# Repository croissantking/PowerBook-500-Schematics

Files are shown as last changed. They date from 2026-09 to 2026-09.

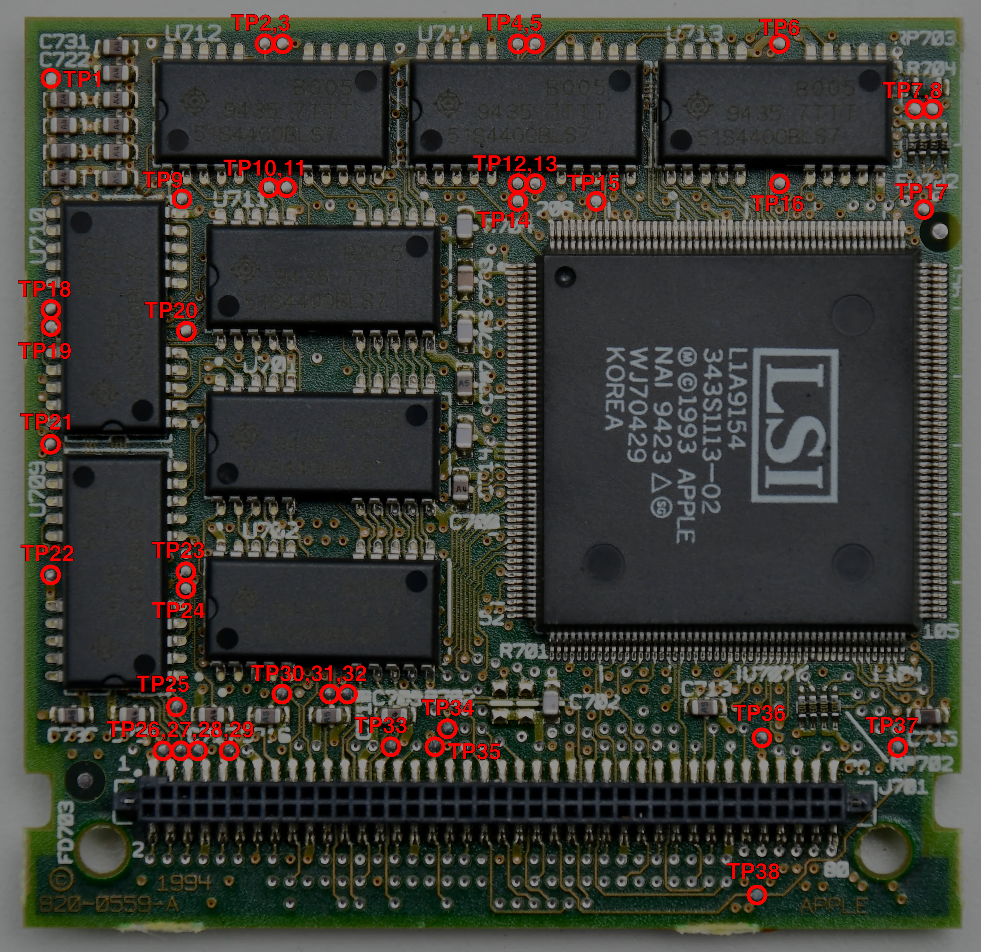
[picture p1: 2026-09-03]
docs/reference/test-points.jpg

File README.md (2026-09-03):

# Macintosh PowerBook 500 Series CPU Card Schematics

The PowerBook 500 Series is a very popular laptop with hobbyists. Lately I have been tinkering a lot with mine. Unfortunately no schematics are available which limits repair and modding potential. In an effort to remedy this, I studied a CPU card with a multimeter and drew up schematics in KiCad.

The CPU card is essentially identical across all five models: the 520, 520c, 540, 540c and 550c.

The drawings are a work in progress so I expect there to be some errors, although hopefully just minor ones.

Follow this link to jump to the [PDF Schematics Directory](https://github.com/croissantking/PowerBook-500-Schematics/tree/main/docs).

### Acknowledgements

With thanks to oldcrap.org for permission to re-use their PowerBook 540c CPU card scans.

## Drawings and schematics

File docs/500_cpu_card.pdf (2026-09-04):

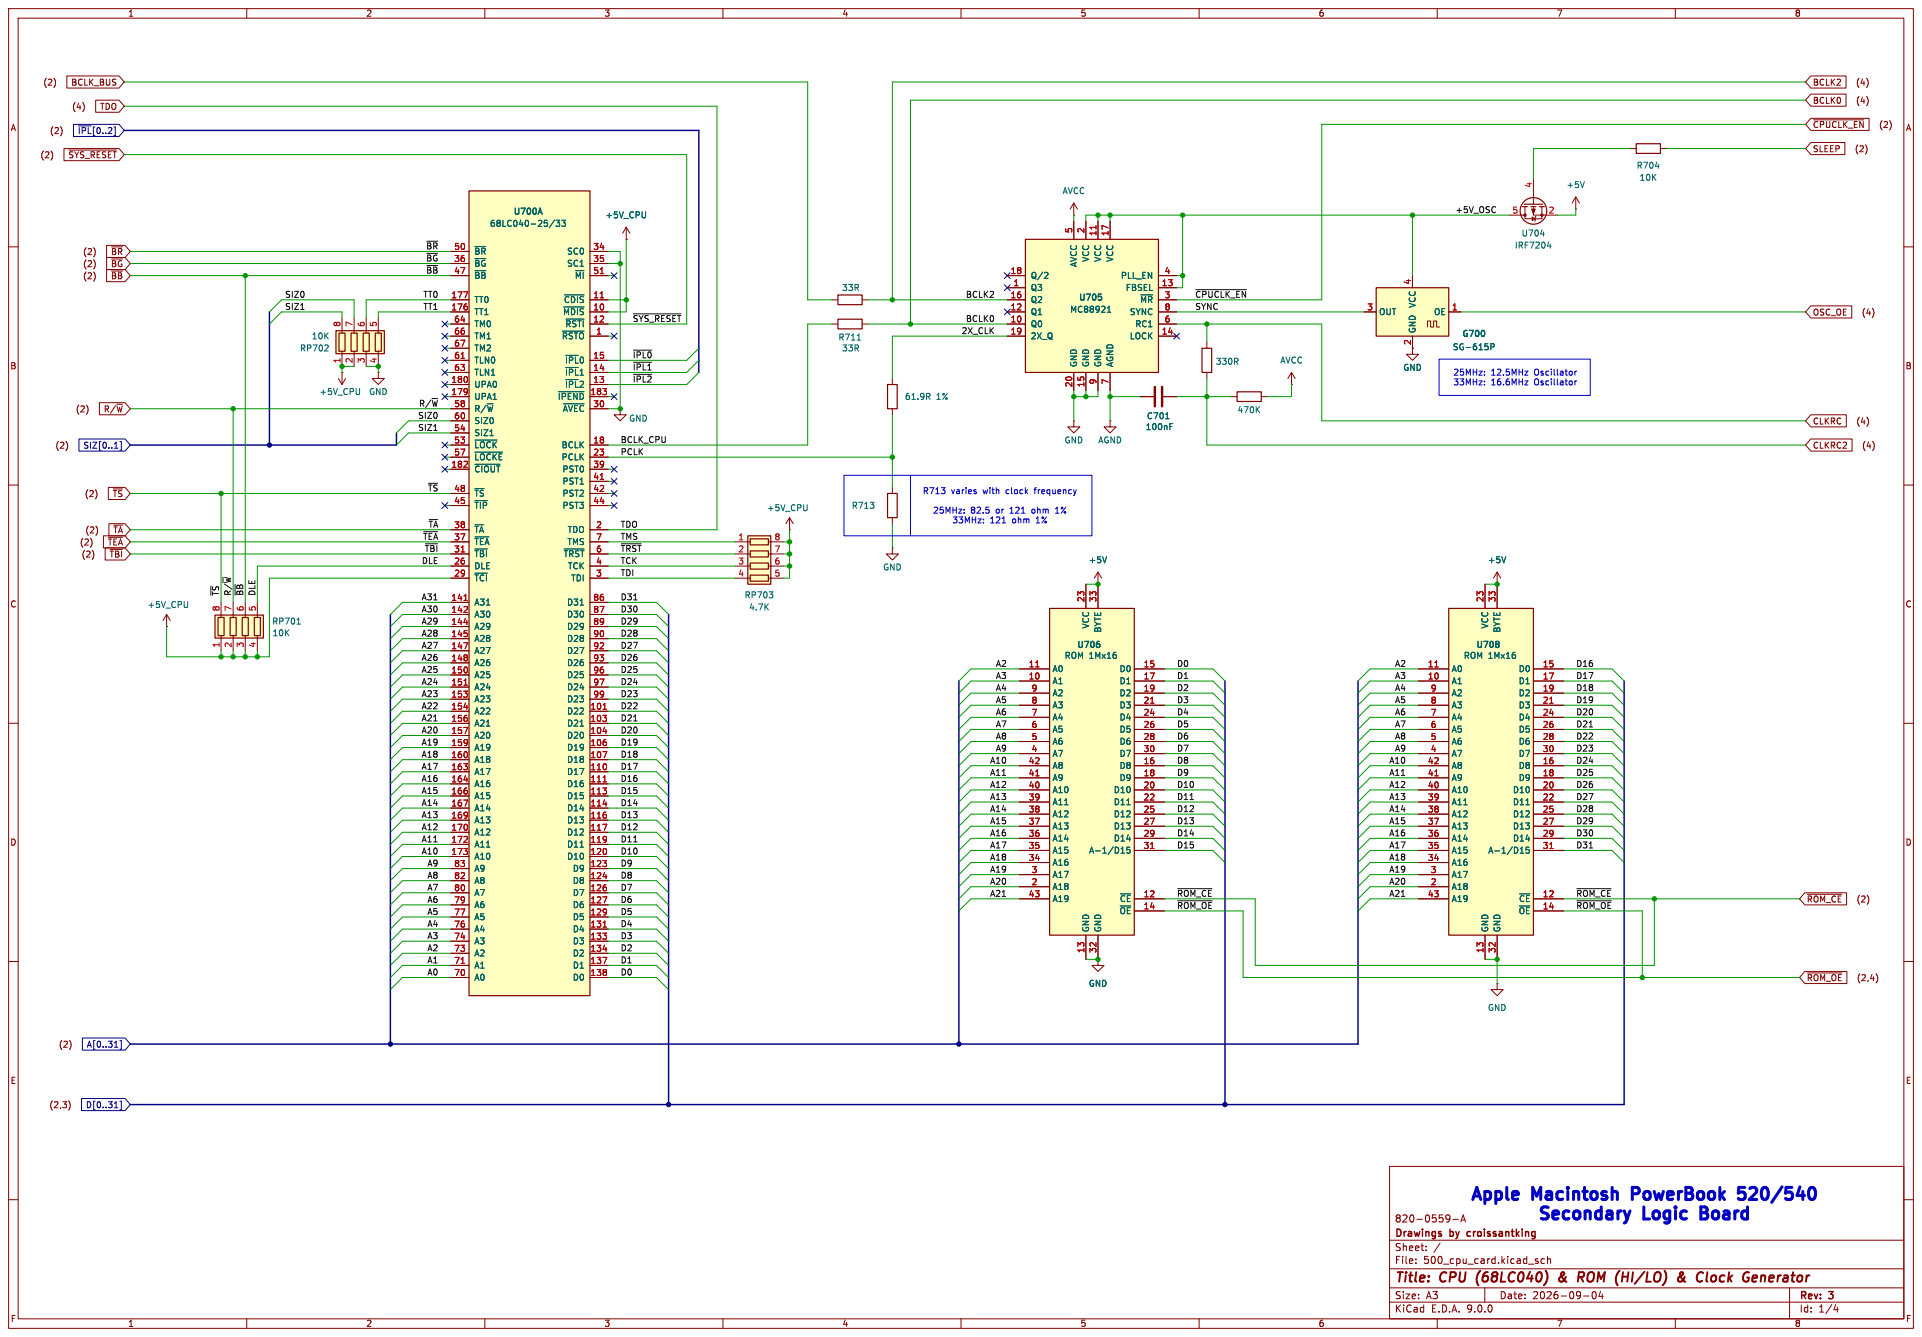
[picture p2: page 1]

~{BR} 50 ~{BG} 36 ~{BB} 47 TT0 177 TT1 176 TM0 64 TM1 66 TM2 67 TLN0 61 TLN1 63 UPA0 180 UPA1 179 R/~{W} 58 SIZ0 60 SIZ1 54 ~{LOCK} 53 ~{LOCKE} 57 ~{CIOUT} 182 ~{TS} 48 ~{TIP} 45 ~{TA} 38 ~{TEA} 37 ~{TBI} 31 DLE 26 ~{TCI} 29 A31 141 A30 142 A29 144 A28 145 A27 147 A26 148 A25 150 A24 151 A23 153 A22 154 A21 156 A20 157 A19 159 A18 160 A17 163 A16 164 A15 166 A14 167 A13 169 A12 170 A11 172 A10 173 A9 83 A8 82 A7 80 A6 79 A5 77 A4 76 A3 74 A2 73 A1 71 A0 70

68LC040-25/33 ~{BR} 50 ~{BG} 36 ~{BB} 47 TT0 177 TT1 176 TM0 64 TM1 66 TM2 67 TLN0 61 TLN1 63 UPA0 180 UPA1 179 R/~{W} 58 SIZ0 60 SIZ1 54 ~{LOCK} 53 ~{LOCKE} 57 ~{CIOUT} 182 ~{TS} 48 ~{TIP} 45 ~{TA} 38 ~{TEA} 37 ~{TBI} 31 DLE 26 ~{TCI} 29 A31 141 A30 142 A29 144 A28 145 A27 147 A26 148 A25 150 A24 151 A23 153 A22 154 A21 156 A20 157 A19 159 A18 160 A17 163 A16 164 A15 166 A14 167 A13 169 A12 170 A11 172 A10 173 A9 83 A8 82 A7 80 A6 79 A5 77 A4 76 A3 74 A2 73 A1 71 A0 70
SC0 34 SC1 35 ~{MI}51 ~{CDIS}11 ~{MDIS}10 ~{RSTI}12 ~{RSTO}1 ~{IPL}015 ~{IPL}114 ~{IPL}213 ~{IPEND}183 ~{AVEC}30 BCLK 18 PCLK 23 PST0 39 PST1 41 PST2 42 PST3 44 TDO 2 TMS 7 ~{TRST}6 TCK 4 TDI 3 D31 86 D30 87 D29 89 D28 90 D27 92 D26 93 D25 96 D24 97 D23 99 D22 101 D21 103 D20 104 D19 106 D18 107 D17 110 D16 111 D15 113 D14 114 D13 116 D12 117 D11 119 D10 120 D9 123 D8 124 D7 126 D6 127 D5 129 D4 131 D3 133 D2 134 D1 137 D0 138

2 GND 15 AVCC
25MHz: 12.5MHz Oscillator 33MHz: 16.6MHz Oscillator Apple Macintosh PowerBook 520/540

A21 R713 varies with clock frequency 25MHz: 82.5 or 121 ohm 1%

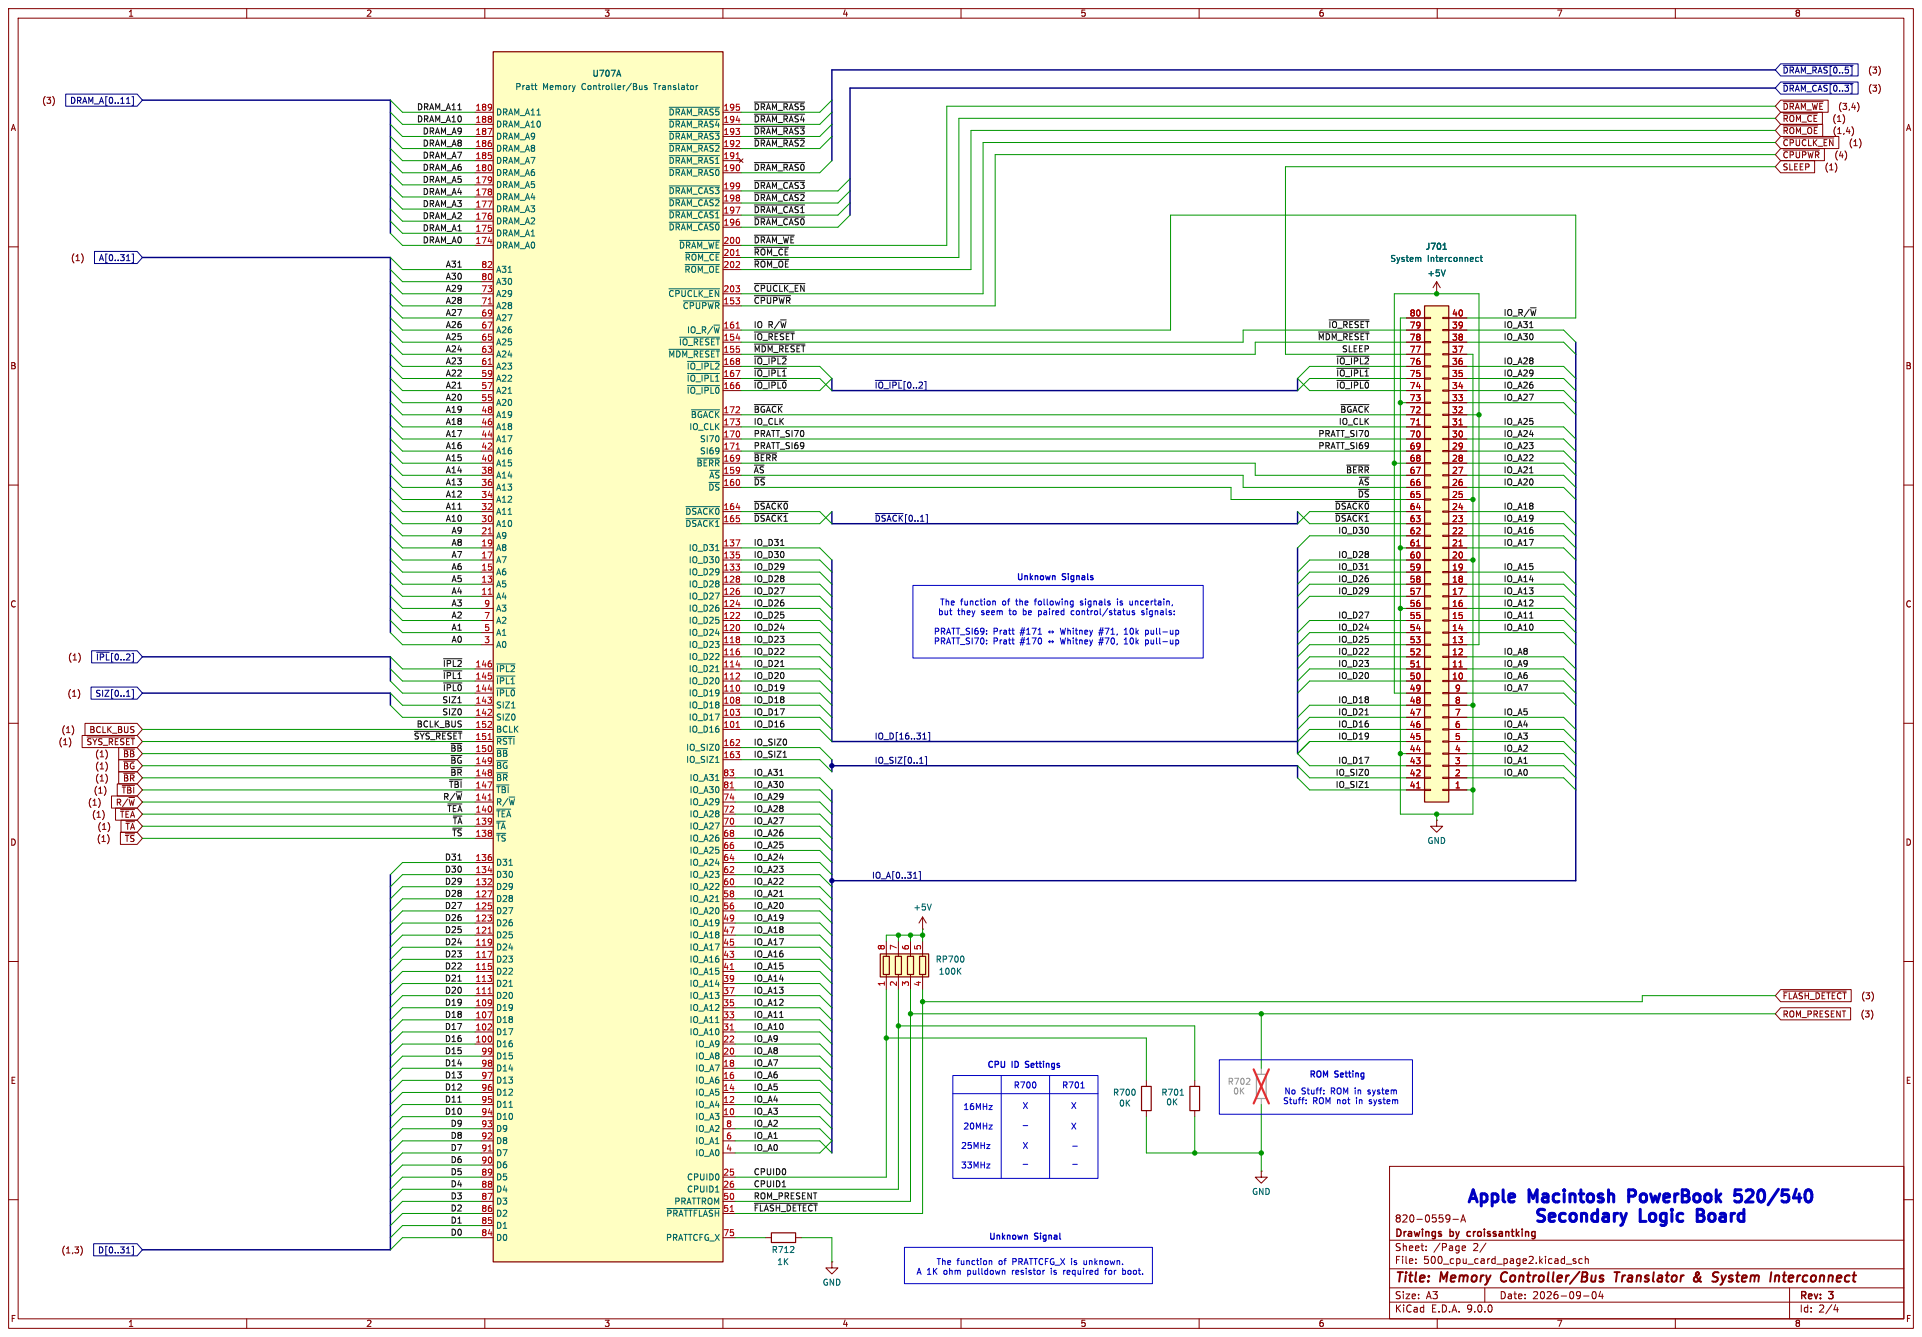
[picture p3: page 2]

Stuff: ROM not in system

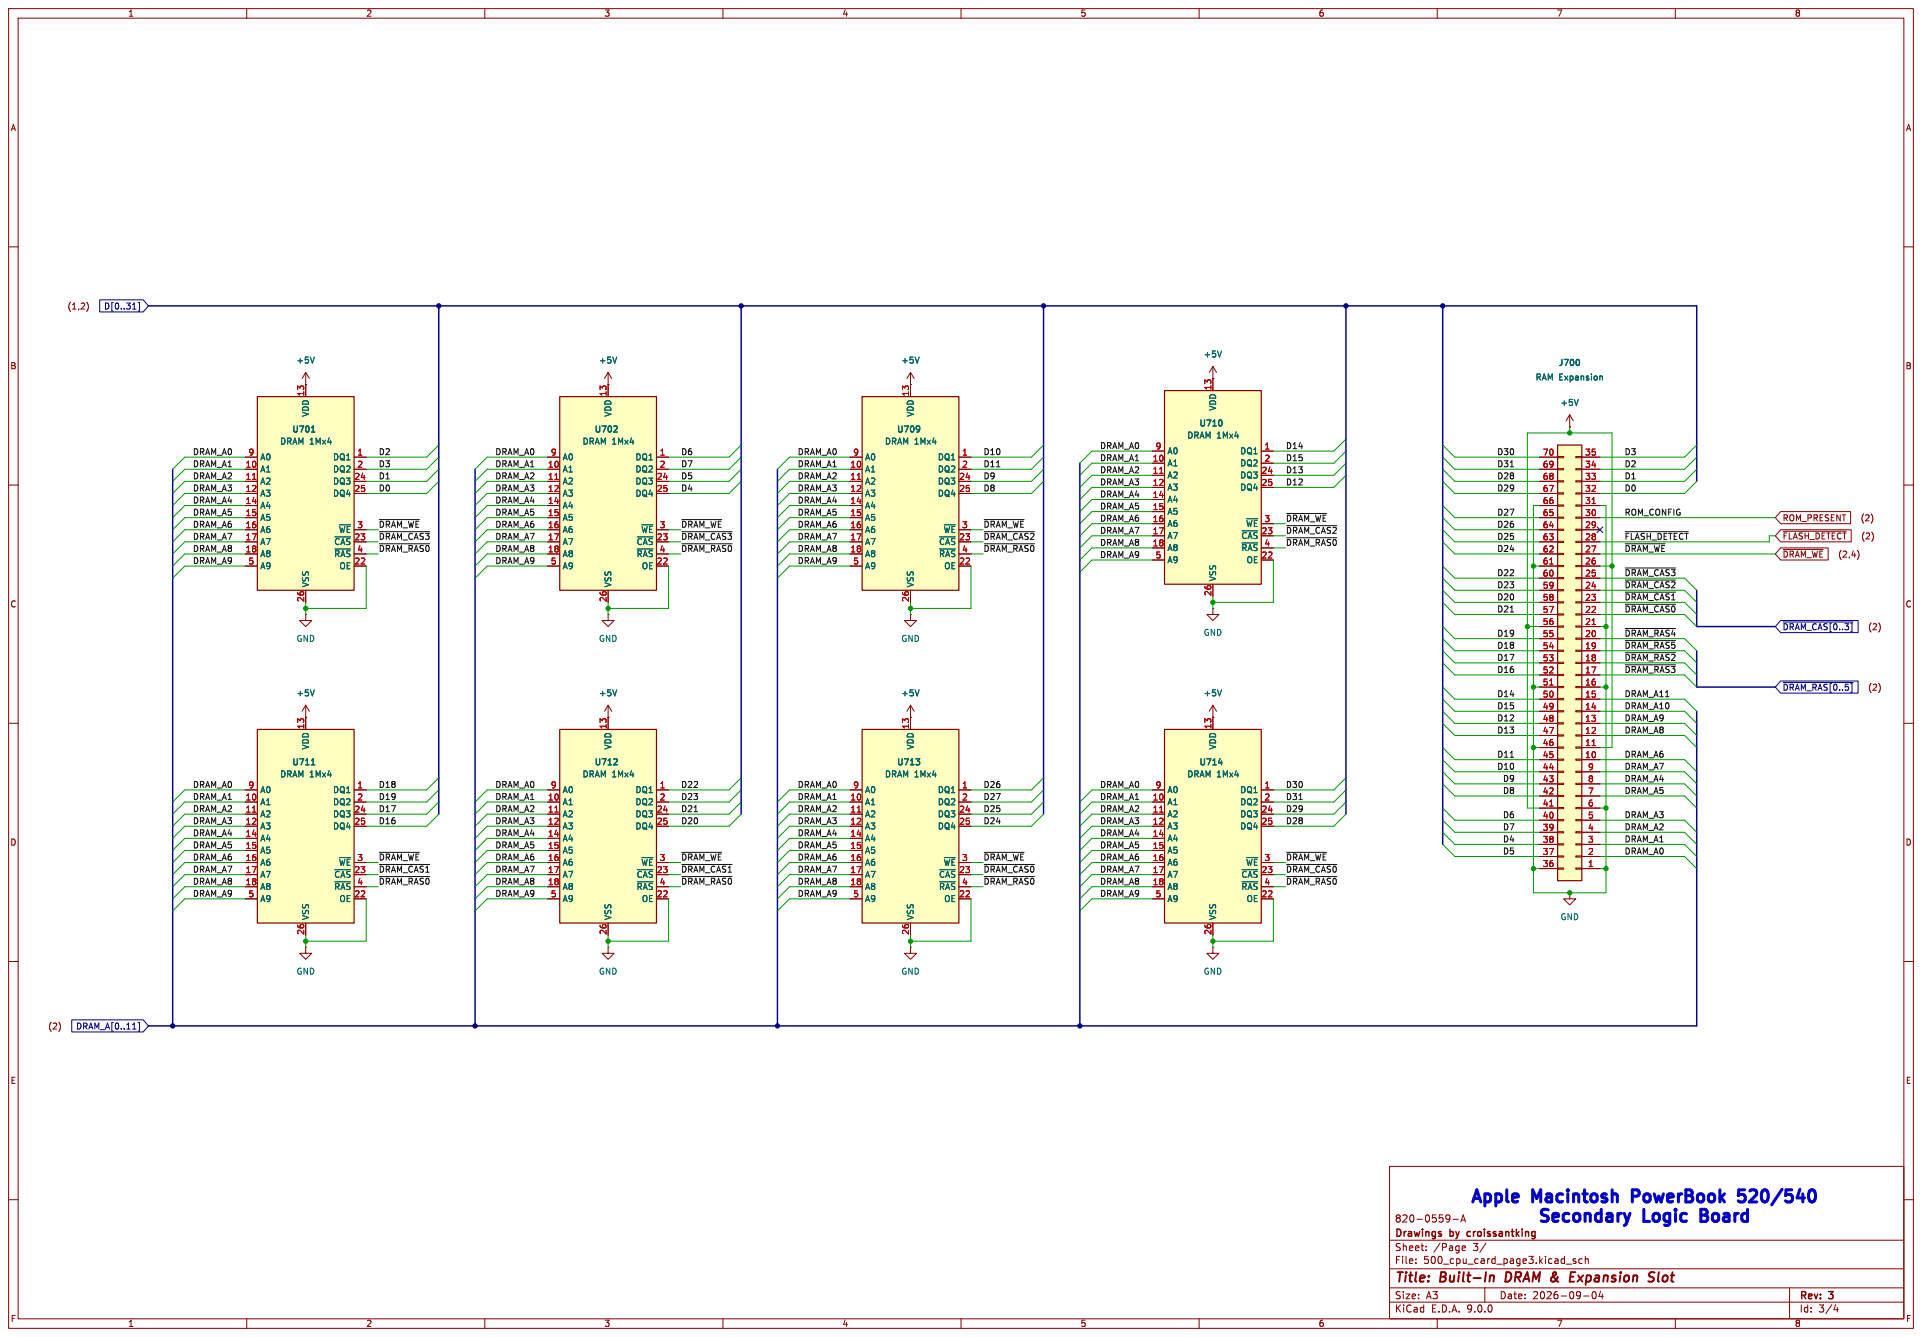
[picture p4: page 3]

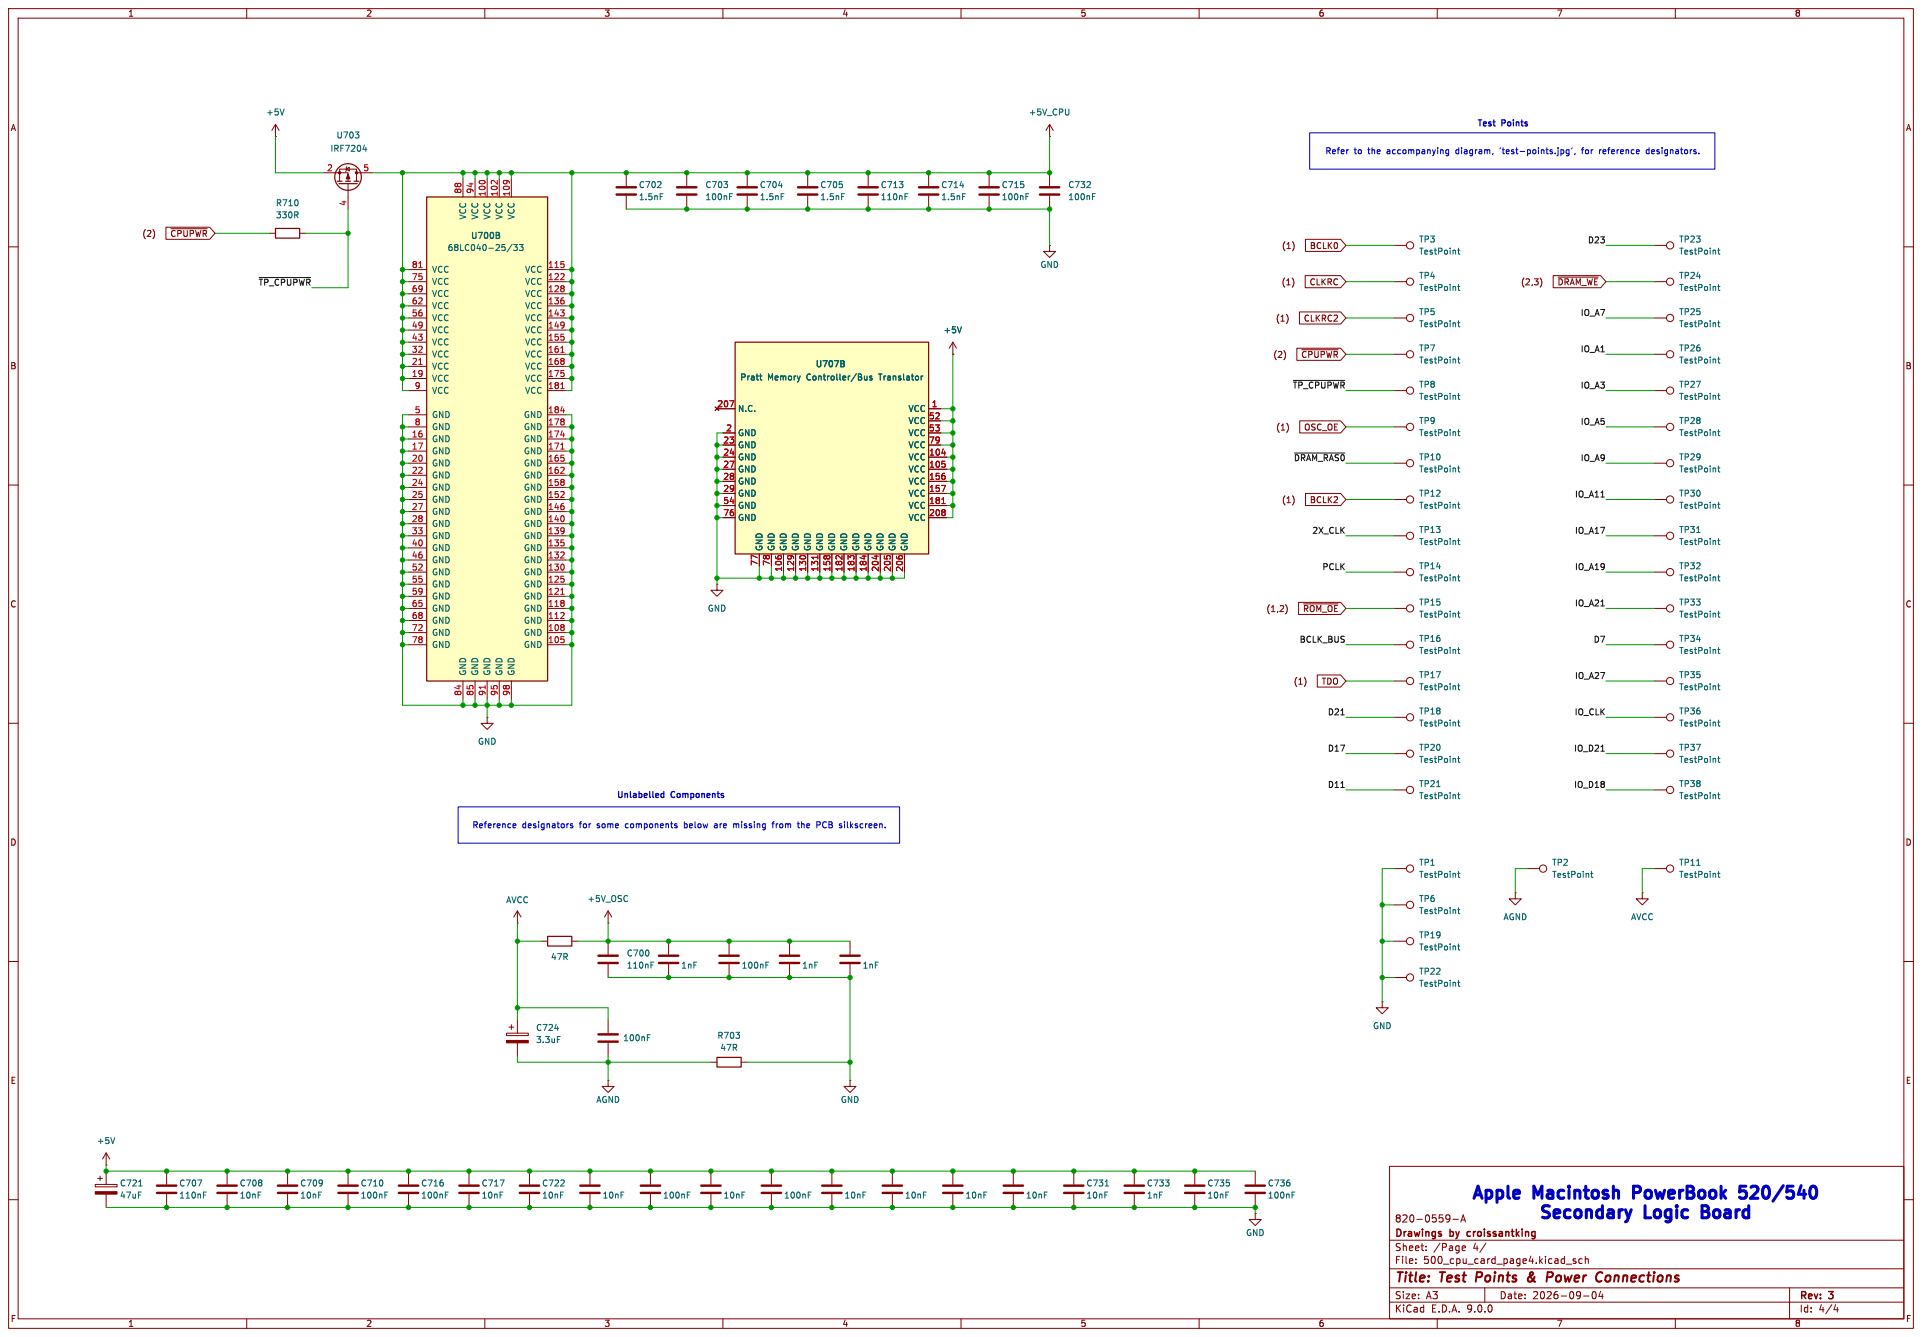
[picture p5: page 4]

TP38 TestPoint TP35 TestPoint TP34 TestPoint TP33 TestPoint TP32 TestPoint TP31 TestPoint C732

TP20 TestPoint TP21 TestPoint TP10 TestPoint TP12 TestPoint TP13 TestPoint

Id: 4/4 Title: Test Points & Power Connections

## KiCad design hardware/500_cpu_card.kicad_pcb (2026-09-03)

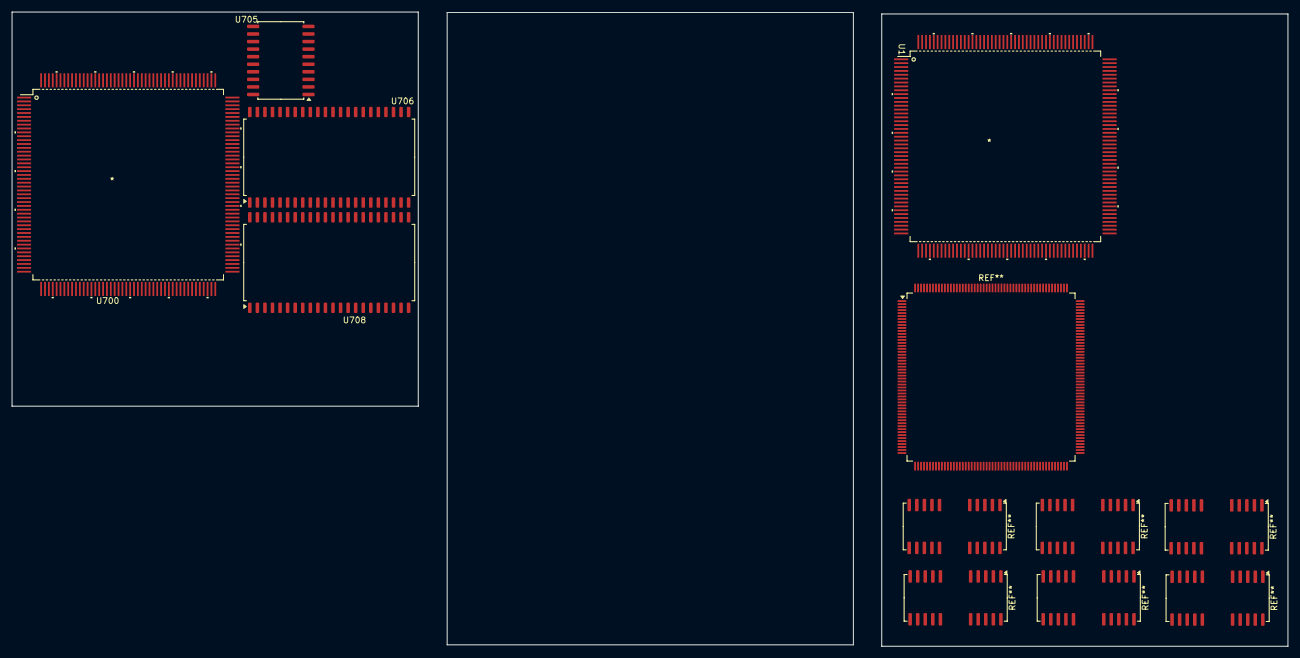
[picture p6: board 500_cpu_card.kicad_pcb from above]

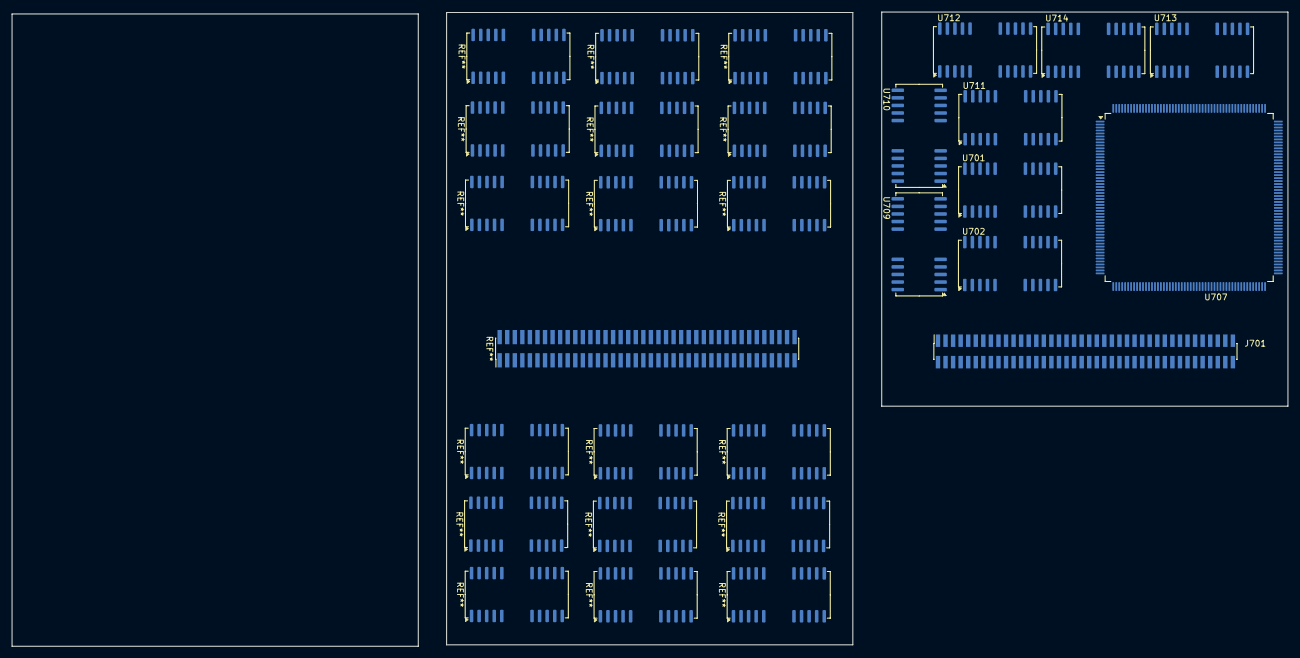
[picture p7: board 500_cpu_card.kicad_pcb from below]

Board: 6 copper layers, 214.3 x 106.5 mm, 15 parts (10 on the bottom side), 161 nets, no tracks yet.

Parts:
J701: System Interconnect; PinSocket_2x40_P1.27mm_Vertical_SMD
U1: MC68040FE; Mot_QFP184_HandSolder
U700: XC68LC040FE25/33; Mot_QFP184_HandSolder
U701, U702, U709, U710, U711, U712, U713, U714: DRAM 1Mx4; SOJ-26
U705: MC88921; SOIC-20W_7.5x12.8mm_P1.27mm
U706, U708: ROM 1Mx16; SOP-44_12.6x28.5mm_P1.27mm
U707: Pratt Memory Controller/Bus Translator; PQFP-208_28x28mm_P0.5mm

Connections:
+5V: J701.13 (VCC), J701.32 (VCC), J701.49 (VCC), J701.68 (VCC), U701.13 (VDD), U702.13 (VDD), U706.23 (VCC), U706.33 (BYTE), U707.1 (VCC), U707.52 (VCC), U707.53 (VCC), U707.79 (VCC), U707.104 (VCC), U707.105 (VCC), U707.156 (VCC), U707.157 (VCC), U707.181 (VCC), U707.208 (VCC), U708.23 (VCC), U708.33 (BYTE), U709.13 (VDD), U710.13 (VDD), U711.13 (VDD), U712.13 (VDD), U713.13 (VDD), U714.13 (VDD)
+5V_CPU: U700.9 (VCC), U700.10 (~MDIS), U700.11 (~CDIS), U700.19 (VCC), U700.21 (VCC), U700.29 (~TCI), U700.32 (VCC), U700.43 (VCC), U700.49 (VCC), U700.56 (VCC), U700.62 (VCC), U700.69 (VCC), U700.75 (VCC), U700.81 (VCC), U700.88 (VCC), U700.94 (VCC), U700.100 (VCC), U700.102 (VCC), U700.109 (VCC), U700.115 (VCC), U700.122 (VCC), U700.128 (VCC), U700.136 (VCC), U700.143 (VCC), U700.149 (VCC), U700.155 (VCC), U700.161 (VCC), U700.168 (VCC), U700.175 (VCC), U700.181 (VCC)
/Page 2/IO_69: J701.69 (?), U707.171 (IO_69)
/Page 2/IO_70: J701.70 (?), U707.170 (IO_70)
/Page 2/IO_A0: J701.2 (030_A0), U707.4 (IO_A0)
/Page 2/IO_A1: J701.3 (030_A1), U707.6 (IO_A1)
/Page 2/IO_A2: J701.4 (030_A2), U707.8 (IO_A2)
/Page 2/IO_A3: J701.5 (030_A3), U707.10 (IO_A3)
/Page 2/IO_A4: J701.6 (030_A4), U707.12 (IO_A4)
/Page 2/IO_A5: J701.7 (030_A5), U707.14 (IO_A5)
/Page 2/IO_A6: J701.10 (030_A6), U707.16 (IO_A6)
/Page 2/IO_A7: J701.9 (030_A7), U707.18 (IO_A7)
/Page 2/IO_A8: J701.12 (030_A8), U707.20 (IO_A8)
/Page 2/IO_A9: J701.11 (030_A9), U707.22 (IO_A9)
/Page 2/IO_A10: J701.14 (030_A10), U707.31 (IO_A10)
/Page 2/IO_A11: J701.15 (030_A11), U707.33 (IO_A11)
/Page 2/IO_A12: J701.16 (030_A12), U707.35 (IO_A12)
/Page 2/IO_A13: J701.17 (030_A13), U707.37 (IO_A13)
/Page 2/IO_A14: J701.18 (030_A14), U707.39 (IO_A14)
/Page 2/IO_A15: J701.19 (030_A15), U707.41 (IO_A15)
/Page 2/IO_A16: J701.22 (030_A16), U707.43 (IO_A16)
/Page 2/IO_A17: J701.21 (030_A17), U707.45 (IO_A17)
/Page 2/IO_A18: J701.24 (030_A18), U707.47 (IO_A18)
/Page 2/IO_A19: J701.23 (030_A19), U707.49 (IO_A19)
/Page 2/IO_A20: J701.26 (030_A20), U707.56 (IO_A20)
/Page 2/IO_A21: J701.27 (030_A27), U707.58 (IO_A21)
/Page 2/IO_A22: J701.28 (030_A22), U707.60 (IO_A22)
/Page 2/IO_A23: J701.29 (030_A23), U707.62 (IO_A23)
/Page 2/IO_A24: J701.30 (030_A24), U707.64 (IO_A24)
/Page 2/IO_A25: J701.31 (030_A25), U707.66 (IO_A25)
/Page 2/IO_A26: J701.34 (030_A36), U707.68 (IO_A26)
/Page 2/IO_A27: J701.33 (030_A27), U707.70 (IO_A27)
/Page 2/IO_A28: J701.36 (030_A28), U707.72 (IO_A28)
/Page 2/IO_A29: J701.35 (030_A29), U707.74 (IO_A29)
/Page 2/IO_A30: J701.38 (030_A30), U707.81 (IO_A30)
/Page 2/IO_A31: J701.39 (030_A31), U707.83 (IO_A31)
/Page 2/IO_CLK: J701.71 (IO_CLK), U707.173 (IO_CLK)
/Page 2/IO_D16: J701.46 (030_D16), U707.101 (IO_D16)
/Page 2/IO_D17: J701.43 (030_D17), U707.103 (IO_D17)
/Page 2/IO_D18: J701.48 (030_D18), U707.108 (IO_D18)
/Page 2/IO_D19: J701.45 (030_D19), U707.110 (IO_D19)
/Page 2/IO_D20: J701.50 (030_D20), U707.112 (IO_D20)
/Page 2/IO_D21: J701.47 (030_D21), U707.114 (IO_D21)
/Page 2/IO_D22: J701.52 (030_D22), U707.116 (IO_D22)
/Page 2/IO_D23: J701.51 (030_D23), U707.118 (IO_D23)
/Page 2/IO_D24: J701.54 (030_D24), U707.120 (IO_D24)
/Page 2/IO_D25: J701.53 (030_D25), U707.122 (IO_D25)
/Page 2/IO_D26: J701.58 (030_D26), U707.124 (IO_D26)
/Page 2/IO_D27: J701.55 (030_D27), U707.126 (IO_D27)
/Page 2/IO_D28: J701.60 (030_D28), U707.128 (IO_D28)
/Page 2/IO_D29: J701.57 (030_D29), U707.133 (IO_D29)
/Page 2/IO_D30: J701.62 (030_D30), U707.135 (IO_D30)
/Page 2/IO_D31: J701.59 (030_D31), U707.137 (IO_D31)
/Page 2/IO_SIZ0: J701.42 (030_SIZ0), U707.162 (IO_SIZ0)
/Page 2/IO_SIZ1: J701.41 (030_SIZ1), U707.163 (IO_SIZ1)
/Page 2/~AS: J701.66 (~AS), U707.159 (~AS)
/Page 2/~BERR: J701.67 (~BERR), U707.169 (~BERR)
/Page 2/~BGACK: J701.72 (~BGACK), U707.172 (~BGACK)
/Page 2/~DSACK0: J701.64 (~DSACK0), U707.164 (~DSACK0)
/Page 2/~DSACK1: J701.63 (~DSACK1), U707.165 (~DSACK1)
/Page 2/~DS: J701.65 (~DS), U707.160 (~DS)
/Page 2/~IO_IPL0: J701.74 (~030_IPL0), U707.166 (~IO_IPL0)
/Page 2/~IO_IPL1: J701.75 (~030_IPL1), U707.167 (~IO_IPL1)
/Page 2/~IO_IPL2: J701.76 (~030_IPL2), U707.168 (~IO_IPL2)
/Page 2/~IO_RESET: J701.79 (~IO_RESET), U707.154 (~IO_RESET)
/Page 2/~MDM_RESET: J701.78 (~MDM_RESET), U707.155 (~MDM_RESET)
/Page 3/A0: U701.9 (A0), U702.9 (A0), U709.9 (A0), U710.9 (A0), U711.9 (A0), U712.9 (A0), U713.9 (A0), U714.9 (A0)
/Page 3/A1: U701.10 (A1), U702.10 (A1), U709.10 (A1), U710.10 (A1), U711.10 (A1), U712.10 (A1), U713.10 (A1), U714.10 (A1)
/Page 3/A2: U701.11 (A2), U702.11 (A2), U709.11 (A2), U710.11 (A2), U711.11 (A2), U712.11 (A2), U713.11 (A2), U714.11 (A2)
/Page 3/A3: U701.12 (A3), U702.12 (A3), U709.12 (A3), U710.12 (A3), U711.12 (A3), U712.12 (A3), U713.12 (A3), U714.12 (A3)
/Page 3/A4: U701.14 (A4), U702.14 (A4), U709.14 (A4), U710.14 (A4), U711.14 (A4), U712.14 (A4), U713.14 (A4), U714.14 (A4)
/Page 3/A5: U701.15 (A5), U702.15 (A5), U709.15 (A5), U710.15 (A5), U711.15 (A5), U712.15 (A5), U713.15 (A5), U714.15 (A5)
/Page 3/A6: U701.16 (A6), U702.16 (A6), U709.16 (A6), U710.16 (A6), U711.16 (A6), U712.16 (A6), U713.16 (A6), U714.16 (A6)
/Page 3/A7: U701.17 (A7), U702.17 (A7), U709.17 (A7), U710.17 (A7), U711.17 (A7), U712.17 (A7), U713.17 (A7), U714.17 (A7)
/Page 3/A8: U701.18 (A8), U702.18 (A8), U709.18 (A8), U710.18 (A8), U711.18 (A8), U712.18 (A8), U713.18 (A8), U714.18 (A8)
/Page 3/A9: U701.5 (A9), U702.5 (A9), U709.5 (A9), U710.5 (A9), U711.5 (A9), U712.5 (A9), U713.5 (A9), U714.5 (A9)
/Page 3/~DRAM_CAS0: U713.23 (~CAS), U714.23 (~CAS)
/Page 3/~DRAM_CAS1: U711.23 (~CAS), U712.23 (~CAS)
/Page 3/~DRAM_CAS2: U709.23 (~CAS), U710.23 (~CAS)
/Page 3/~DRAM_CAS3: U701.23 (~CAS), U702.23 (~CAS)
/Page 3/~DRAM_RAS0: U701.4 (~RAS), U702.4 (~RAS), U709.4 (~RAS), U710.4 (~RAS), U711.4 (~RAS), U712.4 (~RAS), U713.4 (~RAS), U714.4 (~RAS)
/Page 3/~DRAM_WE: U701.3 (~WE), U702.3 (~WE), U709.3 (~WE), U710.3 (~WE), U711.3 (~WE), U712.3 (~WE), U713.3 (~WE), U714.3 (~WE)
/~ROM_CE: U706.12 (~CE), U708.12 (~CE)
/~ROM_OE: U706.14 (~OE), U708.14 (~OE)
A0: U700.70 (A0), U706.11 (A0), U707.3 (A0), U708.11 (A0)
A1: U700.71 (A1), U706.10 (A1), U707.5 (A1), U708.10 (A1)
A2: U700.73 (A2), U706.9 (A2), U707.7 (A2), U708.9 (A2)
A3: U700.74 (A3), U706.8 (A3), U707.9 (A3), U708.8 (A3)
A4: U700.76 (A4), U706.7 (A4), U707.11 (A4), U708.7 (A4)
A5: U700.77 (A5), U706.6 (A5), U707.13 (A5), U708.6 (A5)
A6: U700.79 (A6), U706.5 (A6), U707.15 (A6), U708.5 (A6)
A7: U700.80 (A7), U706.4 (A7), U707.17 (A7), U708.4 (A7)
A8: U700.82 (A8), U706.42 (A8), U707.19 (A8), U708.42 (A8)
A9: U700.83 (A9), U706.41 (A9), U707.21 (A9), U708.41 (A9)
A10: U700.173 (A10), U706.40 (A10), U707.30 (A10), U708.40 (A10)
A11: U700.172 (A11), U706.39 (A11), U707.32 (A11), U708.39 (A11)
A12: U700.170 (A12), U706.38 (A12), U707.34 (A12), U708.38 (A12)
A13: U700.169 (A13), U706.37 (A13), U707.36 (A13), U708.37 (A13)
A14: U700.167 (A14), U706.36 (A14), U707.38 (A14), U708.36 (A14)
A15: U700.166 (A15), U706.35 (A15), U707.40 (A15), U708.35 (A15)
A16: U700.164 (A16), U706.34 (A16), U707.42 (A16), U708.34 (A16)
A17: U700.163 (A17), U706.3 (A17), U707.44 (A17), U708.3 (A17)
A18: U700.160 (A18), U706.2 (A18), U707.46 (A18), U708.2 (A18)
A19: U700.159 (A19), U706.43 (A19), U707.48 (A19), U708.43 (A19)
A20: U700.157 (A20), U707.55 (A20)
A21: U700.156 (A21), U707.57 (A21)
A22: U700.154 (A22), U707.59 (A22)
A23: U700.153 (A23), U707.61 (A23)
A24: U700.151 (A24), U707.63 (A24)
A25: U700.150 (A25), U707.65 (A25)
A26: U700.148 (A26), U707.67 (A26)
A27: U700.147 (A27), U707.69 (A27)
A28: U700.145 (A28), U707.71 (A28)
A29: U700.144 (A29), U707.73 (A29)
A30: U700.142 (A30), U707.80 (A30)
A31: U700.141 (A31), U707.82 (A31)
D0: U700.138 (D0), U701.25 (DQ4), U706.15 (D0), U707.84 (D0)
D1: U700.137 (D1), U701.24 (DQ3), U706.17 (D1), U707.85 (D1)
D2: U700.134 (D2), U701.1 (DQ1), U706.19 (D2), U707.86 (D2)
D3: U700.133 (D3), U701.2 (DQ2), U706.21 (D3), U707.87 (D3)
D4: U700.131 (D4), U702.25 (DQ4), U706.24 (D4), U707.88 (D4)
D5: U700.129 (D5), U702.24 (DQ3), U706.26 (D5), U707.89 (D5)
D6: U700.127 (D6), U702.1 (DQ1), U706.28 (D6), U707.90 (D6)
D7: U700.126 (D7), U702.2 (DQ2), U706.30 (D7), U707.91 (D7)
D8: U700.124 (D8), U706.16 (D8), U707.92 (D8), U709.25 (DQ4)
D9: U700.123 (D9), U706.18 (D9), U707.93 (D9), U709.24 (DQ3)
D10: U700.120 (D10), U706.20 (D10), U707.94 (D10), U709.1 (DQ1)
D11: U700.119 (D11), U706.22 (D11), U707.95 (D11), U709.2 (DQ2)
D12: U700.117 (D12), U706.25 (D12), U707.96 (D12), U710.25 (DQ4)
D13: U700.116 (D13), U706.27 (D13), U707.97 (D13), U710.24 (DQ3)
D14: U700.114 (D14), U706.29 (D14), U707.98 (D14), U710.1 (DQ1)
D15: U700.113 (D15), U706.31 (A-1/D15), U707.99 (D15), U710.2 (DQ2)
D16: U700.111 (D16), U707.100 (D16), U708.15 (D0), U711.25 (DQ4)
D17: U700.110 (D17), U707.102 (D17), U708.17 (D1), U711.24 (DQ3)
D18: U700.107 (D18), U707.107 (D18), U708.19 (D2), U711.1 (DQ1)
D19: U700.106 (D19), U707.109 (D19), U708.21 (D3), U711.2 (DQ2)
D20: U700.104 (D20), U707.111 (D20), U708.24 (D4), U712.25 (DQ4)
D21: U700.103 (D21), U707.113 (D21), U708.26 (D5), U712.24 (DQ3)
D22: U700.101 (D22), U707.115 (D22), U708.28 (D6), U712.1 (DQ1)
D23: U700.99 (D23), U707.117 (D23), U708.30 (D7), U712.2 (DQ2)
D24: U700.97 (D24), U707.119 (D24), U708.16 (D8), U713.25 (DQ4)
D25: U700.96 (D25), U707.121 (D25), U708.18 (D9), U713.24 (DQ3)
D26: U700.93 (D26), U707.123 (D26), U708.20 (D10), U713.1 (DQ1)
D27: U700.92 (D27), U707.125 (D27), U708.22 (D11), U713.2 (DQ2)
D28: U700.90 (D28), U707.127 (D28), U708.25 (D12), U714.25 (DQ4)
D29: U700.89 (D29), U707.132 (D29), U708.27 (D13), U714.24 (DQ3)
D30: U700.87 (D30), U707.134 (D30), U708.29 (D14), U714.1 (DQ1)
D31: U700.86 (D31), U707.136 (D31), U708.31 (A-1/D15), U714.2 (DQ2)
GND: J701.1 (GND), J701.8 (GND), J701.20 (GND), J701.25 (GND), J701.37 (GND), J701.44 (GND), J701.56 (GND), J701.61 (GND), J701.73 (GND), J701.80 (GND), U700.5 (GND), U700.8 (GND), U700.16 (GND), U700.17 (GND), U700.20 (GND), U700.22 (GND), U700.24 (GND), U700.25 (GND), U700.27 (GND), U700.28 (GND), U700.30 (~AVEC), U700.33 (GND), U700.34 (SC0), U700.35 (SC1), U700.40 (GND), U700.46 (GND), U700.52 (GND), U700.55 (GND), U700.59 (GND), U700.65 (GND), U700.68 (GND), U700.72 (GND), U700.78 (GND), U700.84 (GND), U700.85 (GND), U700.91 (GND), U700.95 (GND), U700.98 (GND), U700.105 (GND), U700.108 (GND), U700.112 (GND), U700.118 (GND), U700.121 (GND), U700.125 (GND), U700.130 (GND), U700.132 (GND), U700.135 (GND), U700.139 (GND), U700.140 (GND), U700.146 (GND), U700.152 (GND), U700.158 (GND), U700.162 (GND), U700.165 (GND), U700.171 (GND), U700.174 (GND), U700.178 (GND), U700.184 (GND), U701.22 (OE), U701.26 (VSS), U702.22 (OE), U702.26 (VSS), U706.13 (GND), U706.32 (GND), U707.2 (GND), U707.23 (GND), U707.24 (GND), U707.27 (GND), U707.28 (GND), U707.29 (GND), U707.54 (GND), U707.76 (GND), U707.77 (GND), U707.78 (GND), U707.106 (GND), U707.129 (GND), U707.130 (GND), U707.131 (GND), U707.158 (GND), U707.182 (GND), U707.183 (GND), U707.184 (GND), U707.204 (GND), U707.205 (GND), U707.206 (GND), U708.13 (GND), U708.32 (GND), U709.22 (OE), U709.26 (VSS), U710.22 (OE), U710.26 (VSS), U711.22 (OE), U711.26 (VSS), U712.22 (OE), U712.26 (VSS), U713.22 (OE), U713.26 (VSS), U714.22 (OE), U714.26 (VSS)
R/~W: U700.58 (R/~W), U707.141 (R/~W)
SIZ0: U700.60 (SIZ0), U707.142 (SIZ0)
SIZ1: U700.54 (SIZ1), U707.143 (SIZ1)
~BB: U700.47 (~BB), U707.150 (~BB)
~BCLK: U700.18 (BCLK), U707.152 (BCLK)
~BG: U700.36 (~BG), U707.149 (~BG)
~BR: U700.50 (~BR), U707.148 (~BR)
~RSTI: U700.12 (~RSTI), U707.151 (~RSTI)
~TA: U700.38 (~TA), U707.139 (~TA)
~TBI: U700.31 (~TBI), U707.147 (~TBI)
~TEA: U700.37 (~TEA), U707.140 (~TEA)
~TS: U700.48 (~TS), U707.138 (~TS)
